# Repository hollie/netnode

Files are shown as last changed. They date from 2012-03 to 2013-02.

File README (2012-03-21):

This is the repository for the netnode project. 

WHAT IS THIS?
-------------

The netnode is an Ethernet-connected microcontroller. It is designed as a generic electronics platform that can be used to automate various tasks in and around the house.

The first version is built around a Microchip PIC microcontroller and a LanTronix XPORT serial to Ethernet convertor.

In this form, the netnode is running for over 5 years at our home. It is used to control electrical blinds, to measure temperatures in our HVAC system, to monitor our solar heating installation, to measure the output of a photovoltaic installation and to interface to wireless sensors.

The latest developments around the netnode focus on adding a standard interface for reporting sensors data and to control basic devices. The selected standard is xPL, because it allows coupling the netnode to a vast amount of existing software such as e.g. Misterhouse.

This repository is divided in three sections: 
 * hardware: the hardware design files of the netnode. The netnode is designed in Eagle and the design is open source (see license below).
 * firmware: the firmware for the controller on the netnode. Currently there is only a single subfolder here. All existing firmware is mapped on a netnode v1.x that is based on a Microchip PIC18F controller.
 * software: various host software packages used to interface to a netnode running a certain firmware. Most of the subfolders here implement a kind of datalogging functionality to RRD databases.
    
AUTHOR
------

Lieven Hollevoet designed the netnode at the time he was building his house. His goal was to build a low-energy home, and setting such a goal of course implies deploying a measurement network to check if the efforts were worthwhile. 
After experimenting with a CAN-based solution, he decided Ethernet was the way to go. The main reasons to go for Ethernet were that the cabling was already present, and that on the computer interface side Ethernet is an interface that is available on every computing device, opposed to CAN which isn't. 

CREDITS
-------

Some 'like-minded' people have contributed to the codebase. 

Dirk Buekenhoudt helped in coding and debugging the xPL interface code. He is currently working on adding digital inputs and outputs.

Roeland Vandebriel wrote the initial code for the SHT7x humidity sensors and is working on merging my Technische Alternative DL output interface code that I initially wrote for my TA UVR61-1. He is working on interfacing to the TA UVR1611.

DEMO
----

A demo of what measurements are done using netnode hardware can be found here:
http://lika.be/uushuus_stats/live.htm

LICENSE
-------

All work in this repository is available under the Creative Commons 
Attribution-NonCommercial-ShareAlike license 3.0.

http://creativecommons.org/licenses/by-nc-sa/3.0/

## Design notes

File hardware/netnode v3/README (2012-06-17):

Specifications of the Netnode v3
================================

Ethernet-connected PIC microcontroller

Highlights:
-----------
* Input voltage: 5 - 30 V, short circuit protected
* 10/100 Ethernet connection configurable through web interface on port 80
* System voltage: 3V3
* Can deliver up to 600 mA to target application.
* Typical power consumption: 0.92 W with ethernet running in normal performance mode
* 8-pin screw terminal connector with 4 GPIOs + ground connected to interrupt pins
* 8-pin screw terminal connector with I2C, 1 PWM, 1 optically isolated input, 1 one-wire bus, 3V3 and GND 
* 4 analog input pins broken out to non-populated header
* ICSP header on board
* Second serial port broken out to header to be able to easily connect XBee radio modules
* PIC has bootloader that allows firmware upgrades over the ethernet interface (*)
* optically isolated input designed for 12V input level (level can be changed by replacing a resistor)
* Open hardware, you're invited to thinker with it. 

Description:
------------
This is a PIC board that was developed to monitor the energy consumption and temperatures in and around our house. Multiple firmwares are available that can be loaded to have the board perform the functionality that is required.

Available firmwares are:
------------------------
 * one-wire to xPL bridge. Allows connecting one-wire temperature sensors, reports their status over xPL for easy integration with existing xPL software (e.g. Misterhouse). Plug the device in your network and the sensors appear in the software.
 * one-wire and SHTxx relative humidity to Cosm bridge. Idem as previous, but reports the sensor status to Cosm.com (previously Pachube). Ideal for people that don't have or want to keep a home server running to report sensor values to Cosm.
 * Technische Alternative solar heating controller interface (TA UVR61-3 and alike). Reports the status of your controller and the attached sensors over xPL (*).
 * TA to Cosm bridge. Idem as previous but reports to Cosm.com instead (*).

*: to be implemented

All work in this folder is available under the Creative Commons 
Attribution-NonCommercial-ShareAlike license 3.0.

http://creativecommons.org/licenses/by-nc-sa/3.0/

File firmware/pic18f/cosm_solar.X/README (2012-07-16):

This firmware turns the Netnode into a device that reports solar installation production to Cosm.com

The idea is to connect the netnode to the pulse output of the solar energy production meter.

This code is developed by Lieven Hollevoet. More info on http://likatronix.be

This work is licensed under the following license: 
  http://creativecommons.org/licenses/by-nc-sa/3.0/

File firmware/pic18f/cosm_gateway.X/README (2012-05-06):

This firmware turns the Netnode into a sensor device that reports status to Cosm.com

It supports Sensirion SHTxx relative humidity sensors, pulse counts, and OneWire temperature devices.

Example feed:
https://cosm.com/feeds/55686

This code is developed by Lieven Hollevoet. More info on http://likatronix.be

This work is licensed under the following license: 
  http://creativecommons.org/licenses/by-nc-sa/3.0/

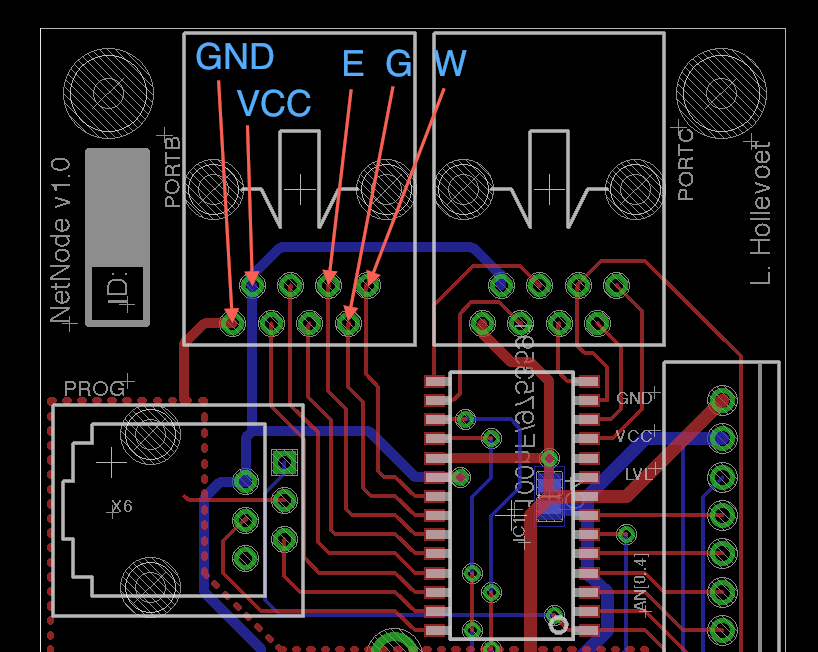
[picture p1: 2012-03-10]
firmware/pic18f/utility_monitor/doc/connections_netnode.png

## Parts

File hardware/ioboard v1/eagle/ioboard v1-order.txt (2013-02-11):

Order list for /Users/lieven/projects/likatronix/netnode/hardware/ioboard v1/eagle/ioboard v1.sch
Exported from EAGLE with DesignLink

Quantity	Value	Package	Order code	Manufacturer	Manuf. Code	Availability	Price (from)	Description
2		C0805	499158	AVX	08051A100JAT2A	4021	0.023	AVX - 08051A100JAT2A - CAPACITOR, 0805, 10PF, 100V
1	MCP23017SO	SO28W	1332087	MICROCHIP	MCP23017-E/SO	2802	0.86	MICROCHIP - MCP23017-E/SO - 16BIT EXPANDER, I/O, I2C I'F, SMD
1		DIL18	1047761	TOSHIBA	ULN2803APG	3340	0.86	TOSHIBA - ULN2803APG - DARLINGTON ARRAY 8NPN, DIP18, 50V
2	ACPL-244	SO16	1634755	AVAGO TECHNOLOGIES	ACPL-244-500E	2927	0.81	AVAGO TECHNOLOGIES - ACPL-244-500E - OPTOCOUPLER, QUAD, AC I/P, SO-16
2	691402910008	691402910008	unknown					
1	61300611021	61300611021	unknown					
1	613006143121	613006143121	unknown					
1	691214110003	691214110003	1841251	WURTH ELEKTRONIK	691214110003	175	0.71	WURTH ELEKTRONIK - 691214110003 - T/BLOCK, 3.5MM, HORIZ, PCB, 3WAY
16		CHIPLED_1206	unknown					
1		R0805	unknown					
7		RN8P-4R-CRA06S	unknown					
1		SJ	unknown					
1	418127270903	418127270903	unknown

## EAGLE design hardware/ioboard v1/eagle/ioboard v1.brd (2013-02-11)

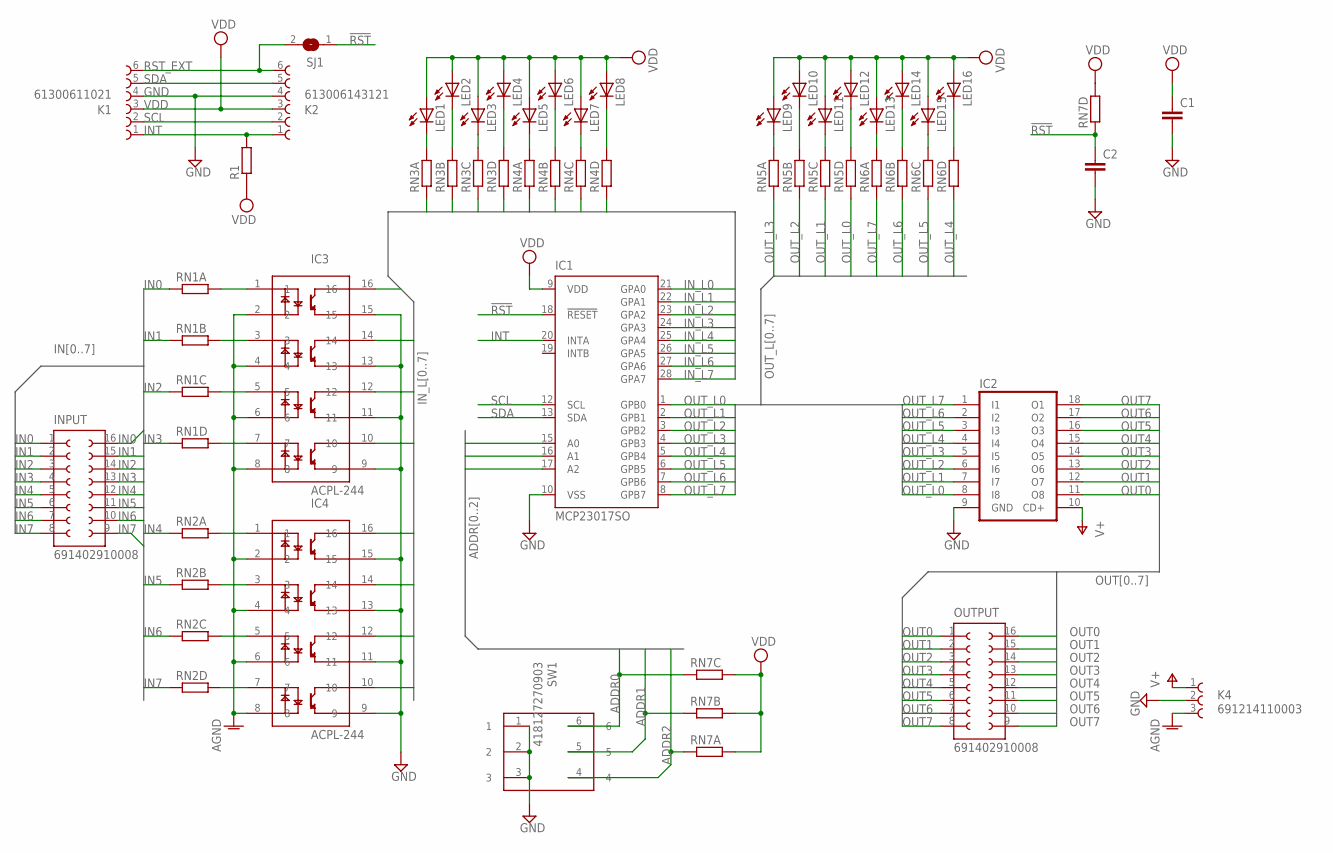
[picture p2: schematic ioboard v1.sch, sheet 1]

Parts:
C1, C2: C-EUC0805; C0805; MPN 08051A100JAT2A
IC1: MCP23017SO; SO28W; MPN MCP23017-E/SO
IC2: ULN2803A; DIL18; MPN ULN2803APG
IC3, IC4: ACPL-244; SO16; MPN ACPL-244-500E
INPUT: 691402910008
K1: 61300611021
K2: 613006143121
K4: 691214110003; MPN 691214110003
LED1, LED2, LED3, LED4, LED5, LED6, LED7, LED8, LED9, LED10, LED11, LED12, LED13, LED14, LED15, LED16: LEDCHIPLED_1206; CHIPLED_1206
OUTPUT: 691402910008
R1: R-EU_R0805; R0805
RN1, RN2, RN3, RN4, RN5, RN6, RN7: RESISTOR_ARRAY_4; RN8P-4R-CRA06S
SJ1: SJ
SW1: 418127270903

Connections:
!RST: C2.1, IC1.18 (!RESET), RN7.4 (1), SJ1.1
ADDR0: IC1.15 (A0), RN7.3 (1), SW1.6
ADDR1: IC1.16 (A1), RN7.2 (1), SW1.5
ADDR2: IC1.17 (A2), RN7.1, SW1.4
AGND: IC3.2, IC3.4, IC3.6, IC3.8, IC4.2, IC4.4, IC4.6, IC4.8, K4.3
GND: C1.2, C2.2, IC1.10 (VSS), IC2.9 (GND), IC3.9, IC3.11, IC3.13, IC3.15, IC4.9, IC4.11, IC4.13, IC4.15, K1.4, K2.4, K4.2, SW1.1, SW1.2, SW1.3
IN0: INPUT.1, INPUT.16, RN1.1
IN1: INPUT.2, INPUT.15, RN1.2 (1)
IN2: INPUT.3, INPUT.14, RN1.3 (1)
IN3: INPUT.4, INPUT.13, RN1.4 (1)
IN4: INPUT.5, INPUT.12, RN2.1
IN5: INPUT.6, INPUT.11, RN2.2 (1)
IN6: INPUT.7, INPUT.10, RN2.3 (1)
IN7: INPUT.8, INPUT.9, RN2.4 (1)
INT: IC1.20 (INTA), K1.1, K2.1, R1.2
IN_L0: IC1.21 (GPA0), IC3.16, RN3.1
IN_L1: IC1.22 (GPA1), IC3.14, RN3.2 (1)
IN_L2: IC1.23 (GPA2), IC3.12, RN3.3 (1)
IN_L3: IC1.24 (GPA3), IC3.10, RN3.4 (1)
IN_L4: IC1.25 (GPA4), IC4.16, RN4.1
IN_L5: IC1.26 (GPA5), IC4.14, RN4.2 (1)
IN_L6: IC1.27 (GPA6), IC4.12, RN4.3 (1)
IN_L7: IC1.28 (GPA7), IC4.10, RN4.4 (1)
unnamed: IC3.1, RN1.8 (2)
unnamed: IC3.3, RN1.7 (2)
unnamed: IC3.5, RN1.6 (2)
unnamed: IC3.7, RN1.5 (2)
unnamed: IC4.1, RN2.8 (2)
unnamed: IC4.3, RN2.7 (2)
unnamed: IC4.5, RN2.6 (2)
unnamed: IC4.7, RN2.5 (2)
unnamed: LED1.C, RN3.8 (2)
unnamed: LED2.C, RN3.7 (2)
unnamed: LED9.C, RN5.8 (2)
unnamed: LED10.C, RN5.7 (2)
unnamed: LED11.C, RN5.6 (2)
unnamed: LED12.C, RN5.5 (2)
unnamed: LED3.C, RN3.6 (2)
unnamed: LED4.C, RN3.5 (2)
unnamed: LED13.C, RN6.8 (2)
unnamed: LED14.C, RN6.7 (2)
unnamed: LED15.C, RN6.6 (2)
unnamed: LED16.C, RN6.5 (2)
unnamed: LED5.C, RN4.8 (2)
unnamed: LED6.C, RN4.7 (2)
unnamed: LED7.C, RN4.6 (2)
unnamed: LED8.C, RN4.5 (2)
OUT0: IC2.11 (O8), OUTPUT.1, OUTPUT.16
OUT1: IC2.12 (O7), OUTPUT.2, OUTPUT.15
OUT2: IC2.13 (O6), OUTPUT.3, OUTPUT.14
OUT3: IC2.14 (O5), OUTPUT.4, OUTPUT.13
OUT4: IC2.15 (O4), OUTPUT.5, OUTPUT.12
OUT5: IC2.16 (O3), OUTPUT.6, OUTPUT.11
OUT6: IC2.17 (O2), OUTPUT.7, OUTPUT.10
OUT7: IC2.18 (O1), OUTPUT.8, OUTPUT.9
OUT_L0: IC1.1 (GPB0), IC2.8 (I8), RN5.4 (1)
OUT_L1: IC1.2 (GPB1), IC2.7 (I7), RN5.3 (1)
OUT_L2: IC1.3 (GPB2), IC2.6 (I6), RN5.2 (1)
OUT_L3: IC1.4 (GPB3), IC2.5 (I5), RN5.1
OUT_L4: IC1.5 (GPB4), IC2.4 (I4), RN6.4 (1)
OUT_L5: IC1.6 (GPB5), IC2.3 (I3), RN6.3 (1)
OUT_L6: IC1.7 (GPB6), IC2.2 (I2), RN6.2 (1)
OUT_L7: IC1.8 (GPB7), IC2.1 (I1), RN6.1
RST_EXT: K1.6, K2.6, SJ1.2
SCL: IC1.12 (SCL), K1.2, K2.2
SDA: IC1.13 (SDA), K1.5, K2.5
V+: IC2.10 (CD+), K4.1
VDD: C1.1, IC1.9 (VDD), K1.3, K2.3, LED1.A, LED2.A, LED3.A, LED4.A, LED5.A, LED6.A, LED7.A, LED8.A, LED9.A, LED10.A, LED11.A, LED12.A, LED13.A, LED14.A, LED15.A, LED16.A, R1.1, RN7.5 (2), RN7.6 (2), RN7.7 (2), RN7.8 (2)

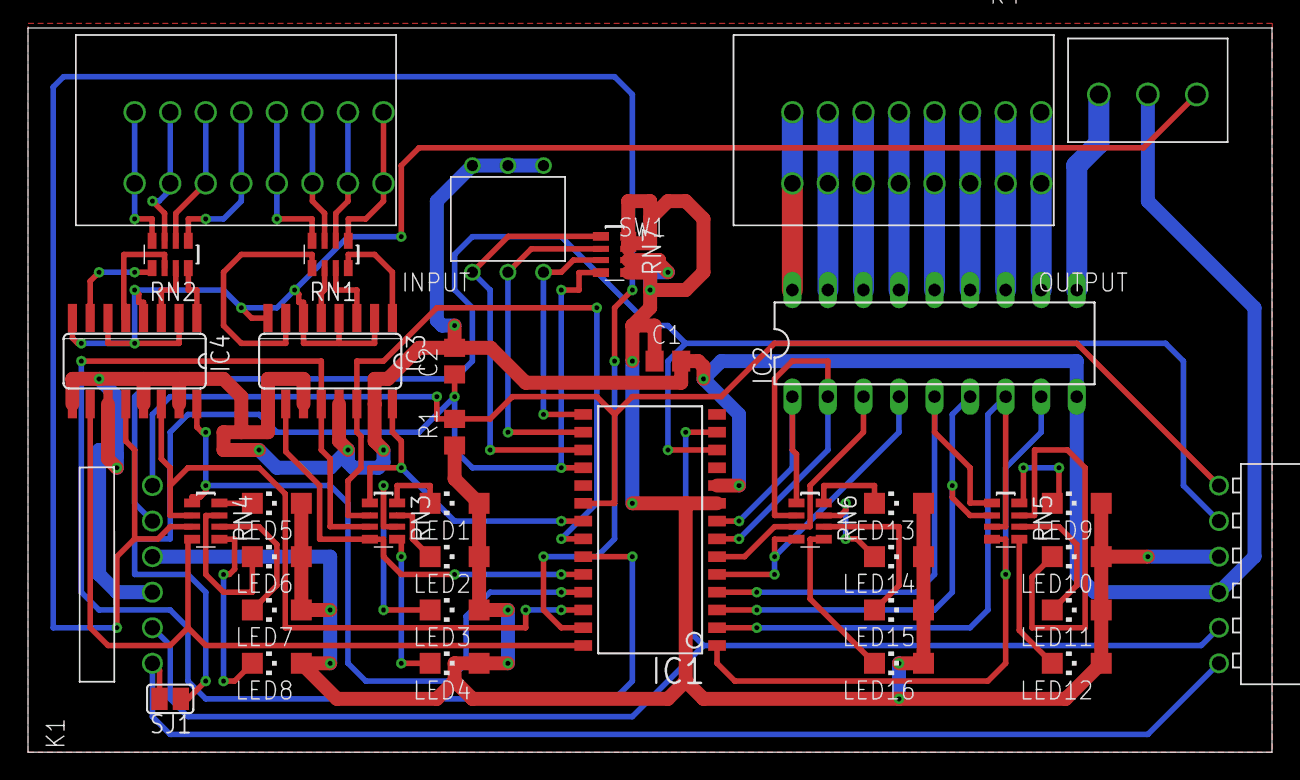
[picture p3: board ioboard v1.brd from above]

Board: 2 copper layers, 88.9 x 51.7 mm, 37 parts (0 on the bottom side), 68 nets.

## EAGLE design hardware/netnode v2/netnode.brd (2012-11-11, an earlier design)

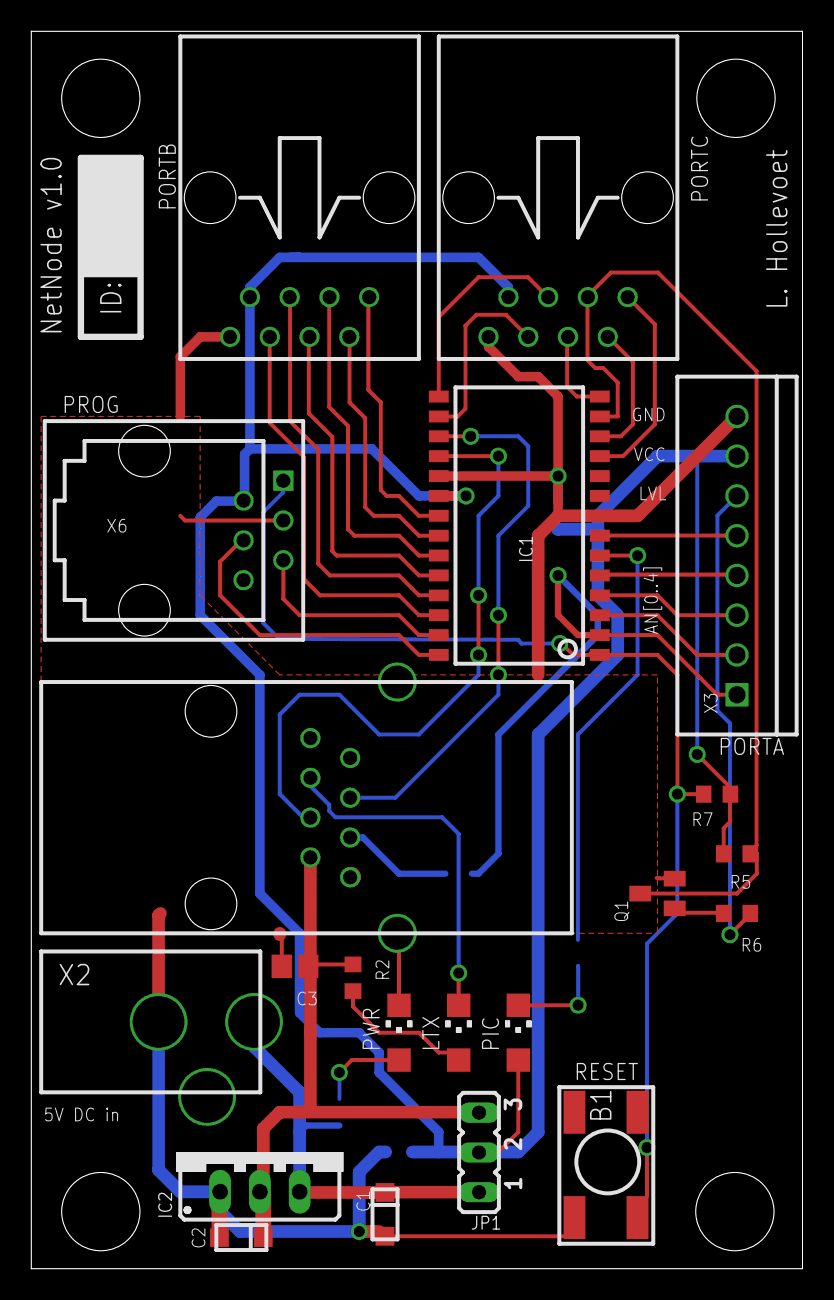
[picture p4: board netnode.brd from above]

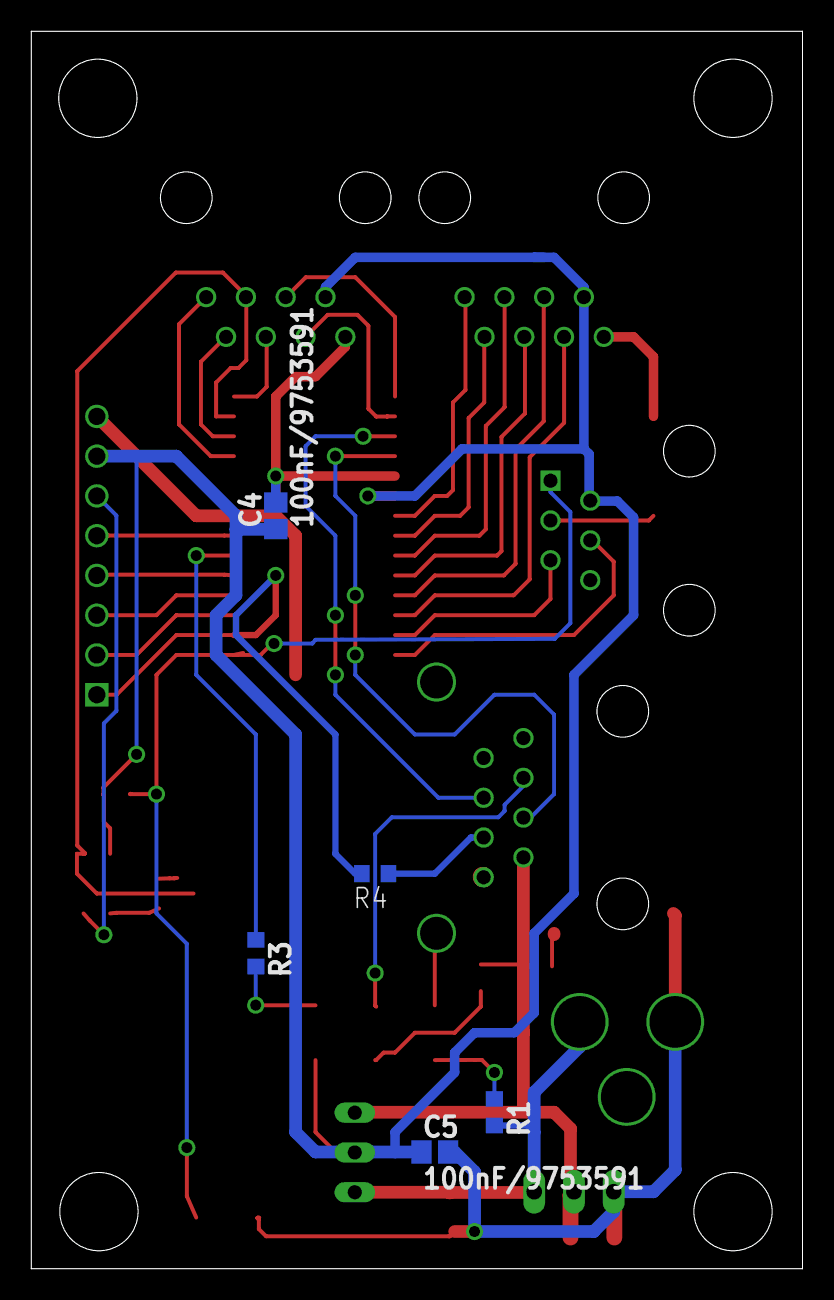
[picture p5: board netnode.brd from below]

Board: 4 copper layers, 49.3 x 79.0 mm, 26 parts (5 on the bottom side), 34 nets.

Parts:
B1: 9902031; PUSHBUTTON
C1, C2: 10u/7565127; CHIPCAP
C3, C4, C5: 100nF/9753591; C0805
IC1: PIC18F2320/9762051; SO-28W
IC2: 1087165; 78XXS
JP1: JP2
LTX: CHIPLED_1206
PIC: CHIPLED_1206
PWR: CHIPLED_1206
Q1: 1081235; SOT23
R1, R2, R3: R0603
R4: 0; R0603
R5: 10k/9331700; R0603
R6: 470k/612807RL; R0603
R7: 1k/9331697RL; R0603
X1: XPORT
X2: DC10R/224959; DC10R
X3: SCREW_TERMINAL/3041438; SCREW_TERMINAL_8PINS
X4, X5: RJ45H
X6: X/1097917; RJ11

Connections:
+3V3: C2.+, C3.1, IC2.GND, JP1.3, R2.2, X1.2
+5V: C1.+, IC2.OUT, JP1.1, R1.2, X2.1
AN0: IC1.2, R4.2, X3.1
AN1: IC1.3, X3.2
AN2: IC1.4, X3.3
AN3: IC1.5, X3.4
AN4: IC1.7, X3.5
CP1: LTX.C, X1.6
GND: B1.1, C1.-, C2.-, C3.2, C4.2, C5.2, IC1.8, IC1.19, IC2.IN, PWR.C, Q1.2, X1.1, X1.TAB1, X1.TAB2, X2.3, X3.8, X4.P$8, X5.P$8, X6.3
LVL: R6.2, X3.6
MCLR: B1.3, IC1.1, R7.2, X6.1
unnamed: Q1.1, R6.1
unnamed: PWR.A, R1.1
unnamed: R4.1, X1.3
unnamed: LTX.A, R2.1
PIC: PIC.C, R3.2
PIC_RX: IC1.18, X1.4
PIC_TX: IC1.17, X1.5
RA4: IC1.6, R3.1
RB0: IC1.21, X4.P$1
RB1: IC1.22, X4.P$2
RB2: IC1.23, X4.P$3
RB3: IC1.24, X4.P$4
RB4: IC1.25, X4.P$5
RB5: IC1.26, X4.P$6
RB6: IC1.27, X6.5
RB7: IC1.28, X6.4
RC0: IC1.11, X5.P$1
RC1: IC1.12, X5.P$2
RC2: IC1.13, Q1.3, R5.1, X5.P$3
RC3: IC1.14, X5.P$4
RC4: IC1.15, X5.P$5
RC5: IC1.16, X5.P$6
VCC: C4.1, C5.1, IC1.20, JP1.2, PIC.A, R5.2, R7.1, X3.7, X4.P$7, X5.P$7, X6.2

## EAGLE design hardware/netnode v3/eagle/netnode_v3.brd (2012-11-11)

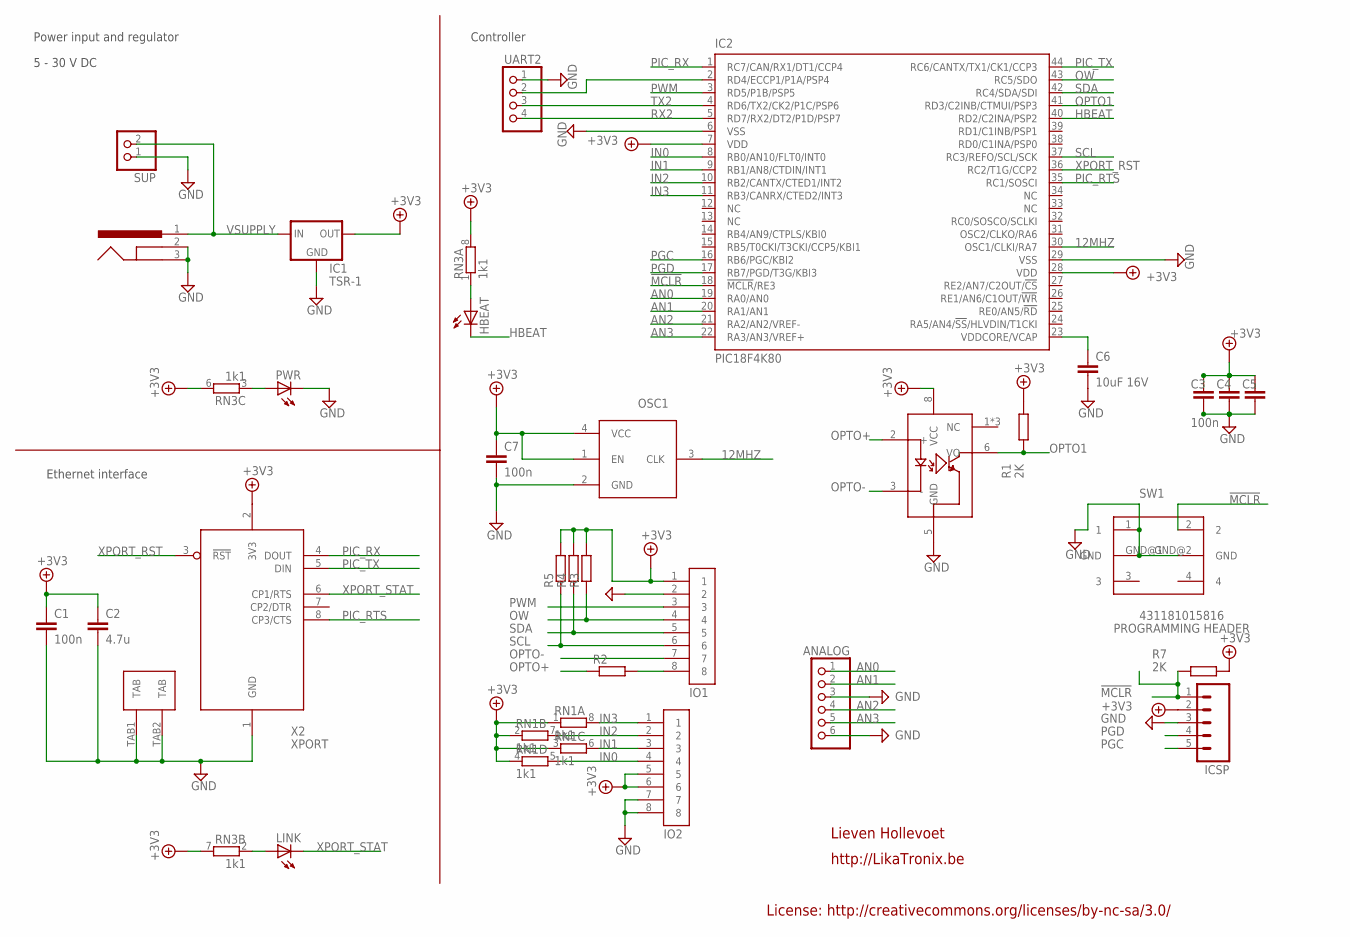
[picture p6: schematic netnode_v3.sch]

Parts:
ANALOG: PINHD-1X6; 1X06
C1, C3, C4, C5, C7: 100n; C0805; MPN 08055C104JAT2A
C2: 4.7u; C0805; MPN 0805YD475KAT2A
C6: 10uF 16V; C1206; MPN C1206C106K4PAC-TU
HBEAT: LEDCHIPLED_1206; CHIPLED_1206; MPN KP-3216EC
IC1: TSR-1; TSR1-SIPS; MPN TSR 1-2433
IC2: PIC18F4K80; TQFP44; MPN PIC18F45K80-I/PT
IC3: FOD060L; SO-08
ICSP: ICSP; 1X05
IO1, IO2: SCREW_TERMINAL; SCREW_TERMINAL_8PINS; MPN 1725711
LINK: LEDCHIPLED_1206; CHIPLED_1206; MPN KP-3216EC
OSC1: TXC - 7X-12.000MBB-T; 7W_7X5; MPN 7X-12.000MBB-T
PWR: LEDCHIPLED_1206; CHIPLED_1206; MPN KP-3216EC
R1, R7: 2K; R0805; MPN CR0603-FX-2001ELF
R2: R-EU_M0805; M0805
R3, R4, R5: R-EU_R0603; R0603
RN1, RN3: 1k1; RN8P-4R-CRA06S; MPN EXB38V102JV
SUP: PINHD-1X2; 1X02
SW1: 431181015816
UART2: PINHD-1X4; 1X04
X1: DC10R; MPN DC10A
X2: XPORT

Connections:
12MHZ: IC2.30 (OSC1/CLKI/RA7), OSC1.3 (CLK)
!MCLR: IC2.18 (!MCLR!/RE3), ICSP.1, R7.1, SW1.2
+3V3: C1.1, C2.1, C3.1, C4.1, C5.1, C7.1, IC1.3 (OUT), IC2.7 (VDD), IC2.28 (VDD), IC3.8 (VCC), ICSP.2, IO1.1, IO2.5, IO2.6, OSC1.1 (EN), OSC1.4 (VCC), R1.2, R3.2, R4.2, R5.2, R7.2, RN1.1, RN1.2 (1), RN1.3 (1), RN1.4 (1), RN3.6 (2), RN3.7 (2), RN3.8 (2), X2.2 (3V3)
AN0: ANALOG.1, IC2.19 (RA0/AN0)
AN1: ANALOG.2, IC2.20 (RA1/AN1)
AN2: ANALOG.4, IC2.21 (RA2/AN2/VREF-)
AN3: ANALOG.5, IC2.22 (RA3/AN3/VREF+)
GND: ANALOG.3, ANALOG.6, C1.2, C2.2, C3.2, C4.2, C5.2, C6.2, C7.2, IC1.2 (GND), IC2.6 (VSS), IC2.29 (VSS), IC3.5 (GND), ICSP.3, IO1.2, IO2.7, IO2.8, OSC1.2 (GND), PWR.C, SUP.1, SW1.1, SW1.GND@1 (GND), SW1.GND@2 (GND), UART2.1, X1.2 (CONTACT), X1.3 (SHIELD), X2.1 (GND), X2.TAB1 (TAB), X2.TAB2 (TAB)
HBEAT: HBEAT.C, IC2.40 (RD2/C2INA/PSP2)
IN0: IC2.8 (RB0/AN10/FLT0/INT0), IO2.4, RN1.5 (2)
IN1: IC2.9 (RB1/AN8/CTDIN/INT1), IO2.3, RN1.6 (2)
IN2: IC2.10 (RB2/CANTX/CTED1/INT2), IO2.2, RN1.7 (2)
IN3: IC2.11 (RB3/CANRX/CTED2/INT3), IO2.1, RN1.8 (2)
unnamed: LINK.A, RN3.2 (1)
unnamed: PWR.A, RN3.3 (1)
unnamed: HBEAT.A, RN3.1
OPTO1: IC2.41 (RD3/C2INB/CTMUI/PSP3), IC3.6 (VO), R1.1
OPTO+: IC3.2 (+), R2.1
OPTO+_PRE_RES: IO1.8, R2.2
OPTO-: IC3.3 (-), IO1.7
OW: IC2.43 (RC5/SDO), IO1.4, R3.1
PGC: IC2.16 (RB6/PGC/KBI2), ICSP.5
PGD: IC2.17 (RB7/PGD/T3G/KBI3), ICSP.4
PIC_RTS: IC2.35 (RC1/SOSCI), X2.8 (CP3/CTS)
PIC_RX: IC2.1 (RC7/CAN/RX1/DT1/CCP4), X2.4 (DOUT)
PIC_TX: IC2.44 (RC6/CANTX/TX1/CK1/CCP3), X2.5 (DIN)
PWM: IC2.3 (RD5/P1B/PSP5), IO1.3
RD4: IC2.2 (RD4/ECCP1/P1A/PSP4), UART2.2
RX2: IC2.5 (RD7/RX2/DT2/P1D/PSP7), UART2.4
SCL: IC2.37 (RC3/REFO/SCL/SCK), IO1.6, R5.1
SDA: IC2.42 (RC4/SDA/SDI), IO1.5, R4.1
TX2: IC2.4 (RD6/TX2/CK2/P1C/PSP6), UART2.3
VDDCAP: C6.1, IC2.23 (VDDCORE/VCAP)
VSUPPLY: IC1.1 (IN), SUP.2, X1.1 (CENTER)
XPORT_RST: IC2.36 (RC2/T1G/CCP2), X2.3 (!RST)
XPORT_STAT: LINK.C, X2.6 (CP1/RTS)

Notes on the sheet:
Power input and regulator
5 - 30 V DC
Ethernet interface
PROGRAMMING HEADER
Lieven Hollevoet
http://LikaTronix.be
License: http://creativecommons.org/licenses/by-nc-sa/3.0/
Controller

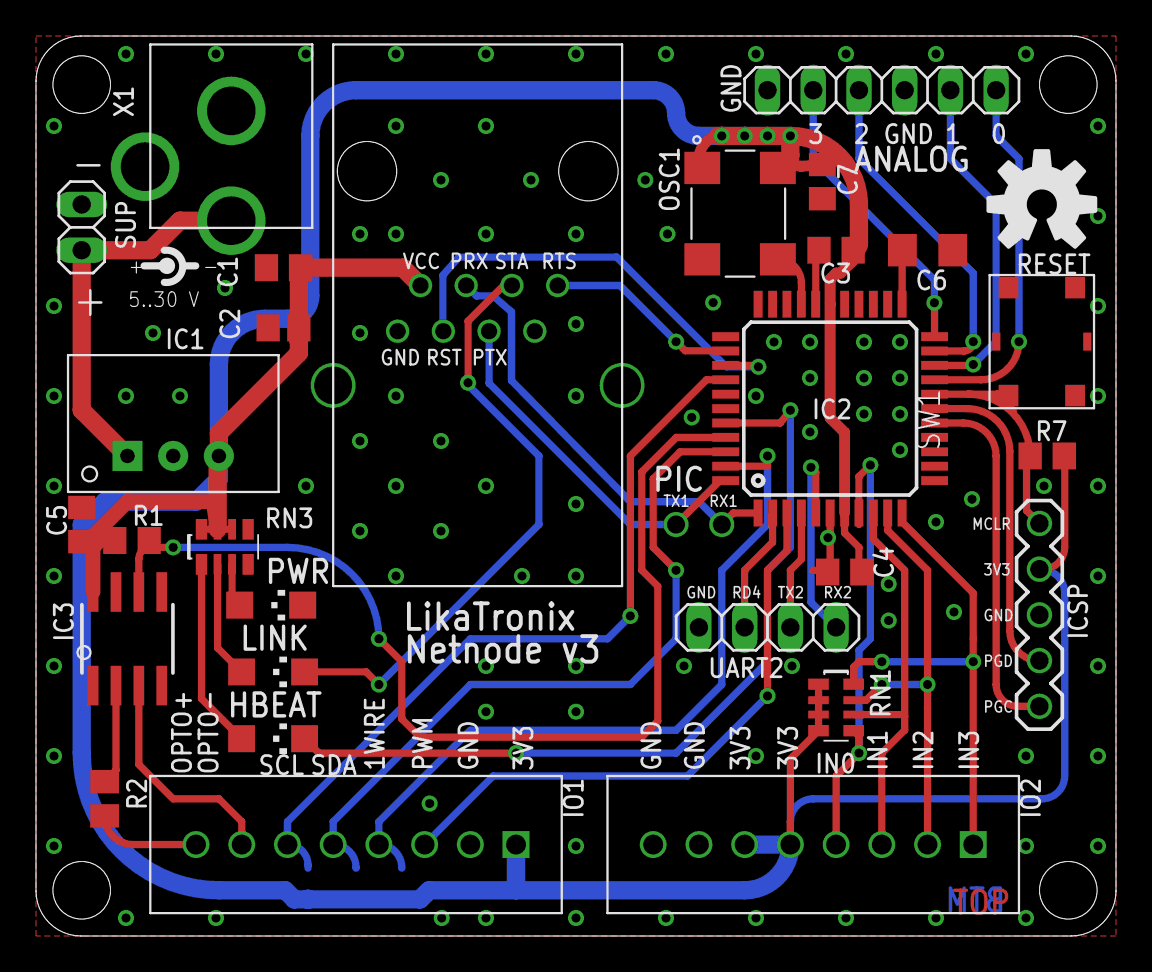
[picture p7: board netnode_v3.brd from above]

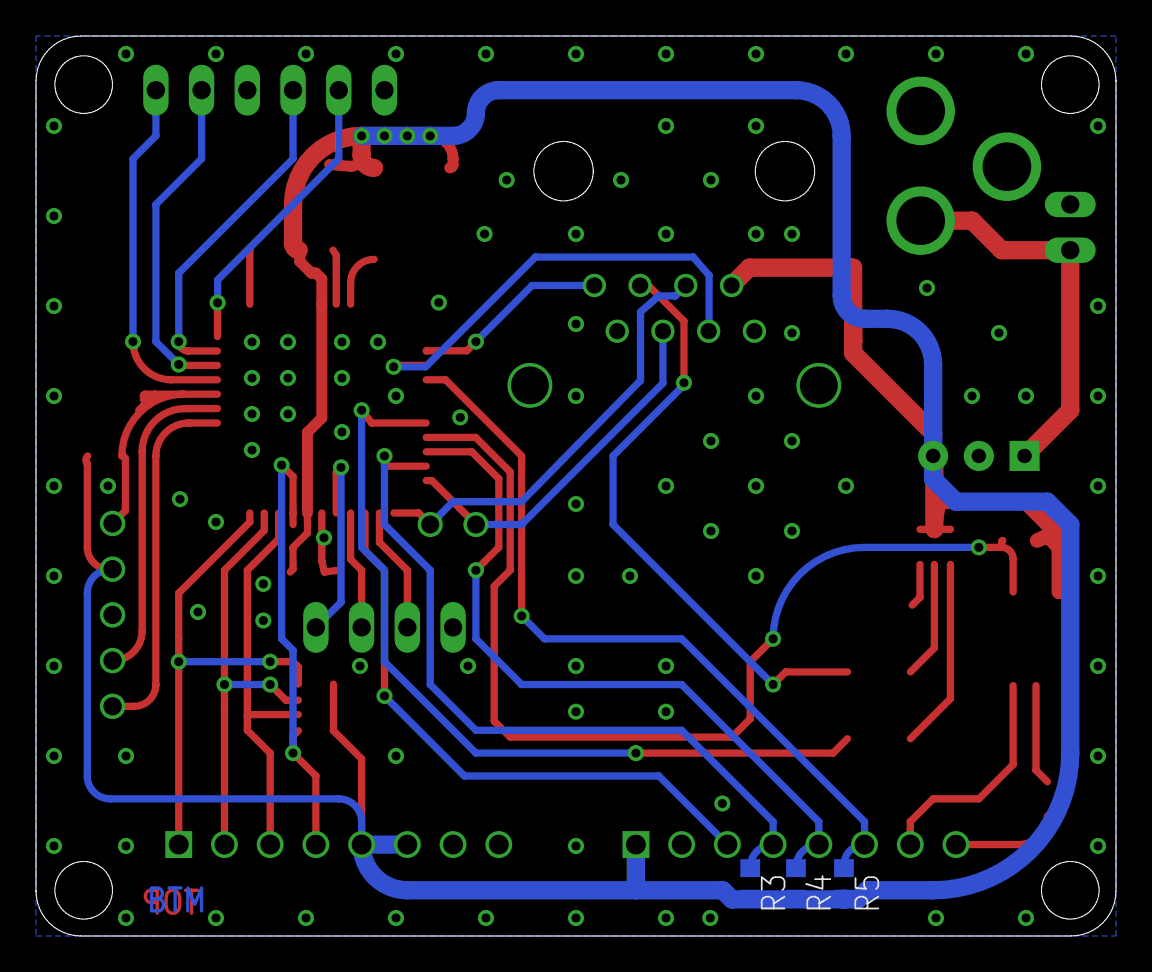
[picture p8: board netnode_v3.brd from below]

Board: 2 copper layers, 60.0 x 50.0 mm, 31 parts (3 on the bottom side), 36 nets.

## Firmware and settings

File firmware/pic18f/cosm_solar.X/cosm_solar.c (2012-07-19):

/*************************************************************
 * Cosm gateway
 *
 * Monitors the inputs INT0..2 and counts pulses on them.
 * Performs debouncing before the count is incremented
 *
 * (c) Lieven Hollevoet, LikaTronix.be
 *
 * License: http://creativecommons.org/licenses/by-nc-sa/3.0/
 **************************************************************
 * target device   : PIC18F2520/PIC18F2580
 * clockfreq       : 32 MHz (internal oscillator + PLL)
 * target hardware : NetNode v2
 * UART speed      : 38400 bps
 * IDE             : MPLABX
 * Compiler        : C18 v3.40
 *************************************************************/

#include <p18cxxx.h>
#include <usart.h>
#include <delays.h>
#include <timers.h>
#include <pwm.h>
#include <stdio.h>

#include "fuses.h"
#include "cosm_solar.h"
#include "../likalibs.X/oo.h"
#include "../likalibs.X/eeprom.h"
#include "../likalibs.X/cosm_socket.h"


// Global variables used for message passing between ISR and main code
// Set time_ticks to 50 so that we try to connect after 10 seconds the first time
volatile unsigned short time_ticks = 350;
volatile unsigned char time_ticks_oo = 0;
volatile unsigned char time_ticks_sht = 0;

volatile unsigned char debounce_water;
volatile unsigned char debounce_gas;
volatile unsigned char debounce_elec;

volatile unsigned short elec_pulses;

enum DEVICE_CONFIGURATION {
    \\
        SHT_PRESENT = 1, \\
        ONE_WIRE_PRESENT = 2, \\
        };

char hw_config = 0; /* mapped with DEVICE_CONFIGURATION
                                            bit 0 = sht_present
                                            bit 1 = one wire present
                    */

char sensor_name[2][12] = {"generated", "dummy"};
//char cosm_api_key[64] = "OivrtCBI0vaCBGTN46ktyluuoqeSAKxzZXlZUEdzdGlRYz0g";
char cosm_api_key[64] = "HelloWorld";

unsigned int cosm_feed_id  = 67597;

//////////////////////////////////////////////////////////////////
// Main loop
// Program strategy:
// * report the sensor status every minute to Cosm.com

void main() {

    signed short sht_temp;
    unsigned char sht_humi;
    unsigned short elec_report;

    // Hardware initialisation
    init();


    // Get configuration settings from EEPROM
    eeprom_read_block(MEM_API_KEY, cosm_api_key, sizeof cosm_api_key);
    //eeprom_write_ulong(MEM_FEED_ID, 67597);
    eeprom_read_block(MEM_FEED_ID, &cosm_feed_id, sizeof cosm_feed_id);

    elec_pulses = 0;
    elec_report = 0;
    // Check presence of sensors
    // Init the helper libraries so that we know if need the
    // library specific code
    /*if (!oo_init()) {
        hw_config |= ONE_WIRE_PRESENT;
        oo_read_temperatures();
    }

    if (sht_init() == 0) {
        hw_config|= SHT_PRESENT;
    }
*/

    // Init the Cosm library
    cosm_init(cosm_api_key, cosm_feed_id);


    while (1) {

        // Check if we need to report (every 5 minutes)
        if (time_ticks > 359) {
            stat0 = 0;
            time_ticks = 0;

            /*

            if (hw_config & SHT_PRESENT) {
                sht_do_measure();
                sht_temp = sht_get_temperature();
                sht_humi = sht_get_humidity();

                cosm_report(sensor_name[0], sht_humi, 0);
                cosm_report(sensor_name[1], sht_temp, 1);

            }
            stat0 = 1;
             */

            // Calculate the average power over the last 5 minute interval
            // and report
            elec_report = elec_pulses;
            cosm_report(sensor_name[0], elec_report*12, 0);
            elec_pulses = elec_pulses - elec_report;


        }

    }

}

//////////////////////////////////////////////////////////////////
// Hardware initialisation routine

void init(void) {

    char blink_count = 0;

    // Oscillator selection
    OSCCONbits.IRCF0 = 1;
    OSCCONbits.IRCF1 = 1;
    OSCCONbits.IRCF2 = 1;
    OSCTUNEbits.PLLEN = 1;

    // All digital IO's on port A
    ADCON1 = 0x0F;

    // Set port direction bits
    TRISA = PortAConfig;
    TRISB = PortBConfig;
    TRISC = PortCConfig;

    // Serial interface init (38400 @ 32 MHz, BRGH = 1 => 51)
    OpenUSART(USART_ASYNCH_MODE &
            USART_TX_INT_OFF &
            USART_RX_INT_ON &
            USART_EIGHT_BIT &
            USART_CONT_RX &
            USART_BRGH_HIGH,
            51);

    // Do the status LED flicker
  /*  while (blink_count++ < 5) {
        Delay10KTCYx(50);
        stat0 = 0;
        Delay10KTCYx(50);
        stat0 = 1;
    }
*/
    // Enable the main 1-sec timer that will interrupt every second
    OpenTimer0(TIMER_INT_ON &
            T0_16BIT &
            T0_SOURCE_INT &
            T0_PS_1_256);

    WriteTimer0(TMR0_VALUE); // Load initial timer value


    // Prepare the 20 ms debouncing timer for the inputs
    OpenTimer1(TIMER_INT_ON &
            T1_16BIT_RW &
            T1_SOURCE_INT &
            T1_PS_1_8 &
            T1_OSC1EN_OFF);

    WriteTimer1(TMR1_VALUE);

    // Enable pullups on Portb inputs
    INTCON2bits.RBPU = 0; // (bit is active low!)

    // Enable interrupt on falling edge of RB0/1/2
    INTCON2bits.INTEDG0 = 0; // Interrupt on falling edge
    INTCON2bits.INTEDG1 = 0; // Interrupt on falling edge
    INTCON2bits.INTEDG2 = 0; // Interrupt on falling edge

    // Reset interrupt flags and enable the interrupts
    INTCONbits.INT0IF = 0; // Reset interrupt
    INTCONbits.INT0IE = 1; // Clear mask bit
    INTCON3bits.INT1IF = 0;
    INTCON3bits.INT1IE = 1;
    INTCON3bits.INT2IF = 0;
    INTCON3bits.INT2IE = 1;

    INTCONbits.PEIE = 1; // Peripheral interrupt enable for USART RX interrupt
    INTCONbits.GIE = 1; // Global interrupt enable

}



//////////////////////////////////////////////////////////////////
// Interrupt service routines
//
// This is some ugly stuff, required by the C18 compiler to ensure
// that the both interrupt vectors contain valid goto instructions

// Generate the high-priority interrupt vector, and put a goto high_isr there
#pragma code high_vector=0x08

void high_interrupt(void) {
    _asm GOTO high_isr _endasm
}

#pragma code

#pragma interrupt high_isr

void high_isr(void) {

    /* USART RX INTERRUPT HANDLING */
    if (PIR1bits.RCIF == 1) {
        cosm_process_uart(ReadUSART());
        PIR1bits.RCIF = 0;
        return;
    }

    /* RB0 INTERRUPT HANDLING */
    if (INTCONbits.INT0IF == 1) {
        debounce_water = 2;
        INTCONbits.INT0IF = 0;
        stat0 = 0;
        return;
    }

    /* RB1 INTERRUPT HANDLING */
    if (INTCON3bits.INT1IF == 1) {
        debounce_gas = 2;
        INTCON3bits.INT1IF = 0;
        stat0 = 0;
        return;
    }

    /* RB2 INTERRUPT HANDLING */
    if (INTCON3bits.INT2IF == 1) {
        debounce_elec = 2;
        INTCON3bits.INT2IF = 0;
        stat0 = 0;
        return;
    }

    /* TIMER 0 INTERRUPT HANDLING */
    if (INTCONbits.TMR0IF == 1) {
        WriteTimer0(TMR0_VALUE); // Reprogram timer
        INTCONbits.TMR0IF = 0; // Clear interrupt flag
        time_ticks++;
        time_ticks_oo++;
        time_ticks_sht++;
    }

    /* TIMER 1 INTERRUPT HANDLING */
    if (PIR1bits.TMR1IF == 1) {
        WriteTimer1(TMR1_VALUE);
        PIR1bits.TMR1IF = 0;
        // Check if we need to handle a debounce
        if (debounce_water) {
            debounce_water--;
            stat0 = 1;
            if (debounce_water == 0 && PORTBbits.RB0 == 0) {
                //xpl_trig(WATER);
            }
        }

        if (debounce_gas) {
            debounce_gas--;
            stat0 = 1;
            if (debounce_gas == 0 && PORTBbits.RB1 == 0) {
                //xpl_trig(GAS);
            }
        }

        if (debounce_elec) {
            debounce_elec--;
            stat0 = 1;
            if (debounce_elec == 0 && PORTBbits.RB2 == 0) {
                //xpl_trig(ELEC);
                elec_pulses++;
            }
        }

    }

    return;
}

// Generate low-priority interrupt vector, and put a goto low_isr there
#pragma code low_vector=0x18

void low_interrupt(void) {
    _asm GOTO low_isr _endasm
}

#pragma code
#pragma interruptlow low_isr

void low_isr(void) {

}

void display_application_menu(char entry){
    switch (entry) {
        case 0:
           printf("Cosm Solar v%i.%i settings menu:\n", VER_MAJOR, VER_MINOR);
           printf("Current settings:\nFeed ID: %i\n", cosm_feed_id);
           printf("API key: %s\n", cosm_api_key);
           printf("Menu:\n\t[1] feed id\n\t[2] API key\n?");
        default:
            printf("Oops, invalid!\n");
    }
}

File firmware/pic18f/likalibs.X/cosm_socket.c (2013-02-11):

/*
 * Connect and send messages to the Cosm.com socket service
 * through a Lantronix XPort device
 *
 * Author: Lieven Hollevoet, LikaTronix.be
 *
 * License: http://creativecommons.org/licenses/by-nc-sa/3.0/
 */

#include <p18cxxx.h>
#include <usart.h>
#include <stdio.h>
#include <delays.h>
#include "cosm_socket.h"

extern void display_application_menu(char entry);

enum UART_STATE_TYPE { IDLE = 0, WAIT_CONNECT, CONNECTED, INCOMING, WAITING_INFO, STORE_STRING, STRING_RECEIVED, WAIT_FOR_DISCONNECT};
enum UART_STATE_TYPE uart_state;
short uart_length;

char* api_key;
unsigned long feed_id;


//////////////////////////////////////////////////////////////////
// Init the library
//////////////////////////////////////////////////////////////////
void cosm_init(char* auth_key, unsigned long feed) {
    uart_length=0;
    uart_state = IDLE;
    api_key = auth_key;
    feed_id = feed;
    return;
}


//////////////////////////////////////////////////////////////////
// Open a TCP connection through the XPORT
//////////////////////////////////////////////////////////////////

void cosm_connect(void) {

    char counter = 0;

    if (uart_state == IDLE) {
        uart_state = WAIT_CONNECT;
        printf("C216.52.233.122/8081\n"); // DNS is not working reliably, so we hardcode the server IP address here
        while (uart_state == WAIT_CONNECT) {
            counter++;
            // Sleep a while
            Delay10KTCYx(80);

            // Timeout, just in case we get stuck here.
            if (counter > 10 ) {
                uart_state = IDLE;
                return;
            }
        }
    }

    return;
}


//////////////////////////////////////////////////////////////////
// Send the current sensor information
// If we want to report a floating point value, we pass the
// value multiplied by 100 and we scale in this function
// by setting the scale value to '1'
//////////////////////////////////////////////////////////////////

void cosm_report(char *name, signed short value, char scale) {

    signed short value_abs;
    signed short value_whole;
    signed short value_part;

    cosm_connect();
    if (uart_state != CONNECTED) {
        return;
    }

    if (scale) {
        value_abs = value;
        if (value < 0) {
            value_abs = -value;
        }
        value_whole =  (value_abs / 100);
        value_part  =  (value_abs - value_whole * 100);
    }

    // Report the sensor value
    printf("{\n\"method\":\"put\",\n");
    printf("\"resource\":\"/feeds/%u\",\n",feed_id);
    printf("\"params\":{},\n");
    printf("\"headers\":{\"X-PachubeApiKey\":\"%s\"},\n", api_key);
    printf("\"body\":{\n \"version\":\"1.0.0\",\n \"datastreams\":[\n {\n  ");
    printf("\"id\":\"%s\",\n  ", name);
    printf("\"current_value\":\"");
    if (scale) {
        if (value < 0) {
            printf("-");
        }
        printf("%i.%02i", value_whole, value_part);
    } else {
        printf("%i", value);
    }
    printf("\"\n }\n ]\n},\n\"token\":\"testing*\"\n}\n");

    return;
}





///////////////////////////////////////////////////////////////////////
// State machine to process that UART input
// This function takes care of the interface towards the XPORT
// that has been put in 'manual connection' mode.
///////////////////////////////////////////////////////////////////////

void cosm_process_uart(char data) {

    uart_length++;

    switch (data) {
        case 'C': // When a connection is made, the XPORT sends a 'C'
            if (uart_state == WAIT_CONNECT || uart_state == IDLE) {
                uart_state = CONNECTED;
            }

            return;
        case 'I': // When the next character is an 'I', it is an active incoming connection. Handle it...
            if (uart_state == CONNECTED && uart_length == 2) {
                uart_state = INCOMING;
                //display_application_menu(0);
            }
            return;
        //case '*': // End of the string that needs to be stored
            //if (uart_state == STORE_STRING){
        //    uart_state = WAIT_FOR_DISCONNECT;
            //}
        //    return;
        case 'D':
            //if (uart_state == WAIT_FOR_DISCONNECT){
                uart_length=0;
                uart_state = IDLE;
            //    return;
            //}
        default:
            switch (uart_state) {
                case WAIT_CONNECT:
                    if (data == 'N') { // If the connection failed, reset the state machine
                        uart_state = IDLE;
                        uart_length = 0;
                        return;
                    }
                    break;
                case INCOMING:
                    if (data == '1') {
                        printf("Waiting for input 1\n");
                    }
                    if (data == '2') {
                        printf("Waiting for input 2\n");
                    }
                    break;
                default:
                    printf("Invalid choice\n");
                    return;

            }

    }

}

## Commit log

2012-03-10 Fixed the compiler warnings caused by different compilation options of the libs vs the code
    [shtxx.h, xpl.c]
2012-03-14 Added support for Sensirion SHTxx humidity sensors.
    Initial support for the sensors is added based on the code migrated by
    Roeland from my PSOC library.
    The readout is working and was reported through a non-standard xPL
    message.
    To be done: add xPL message support conform the specification.
    Bumped the firmware version to v4.6
2012-03-14 Started adding xPL compliant support for the SHT sensor
    Prepared the xPL lib for regularly polling the SHT sensor and to sense
    out xpl-trig messages when the reading changed.
    Bugfix: xpl_node_configuration was mistakingly reset completely in the
    init_instance_id function.
    [shtxx.h, utility_monitor.c, xpl.c]
2012-03-15 Added reporting of the SHT sensor readings to the xPL library
2012-03-15 SHT sensor reporting tested on hardware
2012-05-05 Updated test server for socket client testing
2012-05-12 Corrections for the decimals
    If the decimals where 09 or 0 something they where displayed without
    the 0
    [cosm_socket.c]
2012-05-12 Correct calculation of whole and part value's
    For negative numbers the value_whole and value_part where not
    calculated correctly.
    [cosm_socket.c]
2012-05-15 Added feed id to init function, bug fixed printing of scaled negative values.
    [cosm_gateway.c, cosm_socket.c]
2012-05-15 Updated gitignore and fixed a potential case where we miss the reporting condition due to condition not matching (unlikely, but better to be safe than to be sorry).
    [cosm_gateway.c]
2012-06-11 Intermediate release, schematic to be completed.
    [netnode_v3.brd, netnode_v3.sch]
2012-06-11 Backported bugfix fro Roeland
    [cosm_socket.c]
2012-06-15 Pre-final board files, silkscreen to be fixed
    [netnode_v3.brd, netnode_v3.sch]
2012-07-09 Further finalization of board
    [netnode_v3.brd, netnode_v3.sch]
2012-07-16 Completed order codes.
    [netnode_v3.brd, netnode_v3.sch]
2012-07-16 Added resistors and cleaned silkscreen
    [netnode_v3.brd]
2012-07-19 Further board cleanup
    * Silkscreen fixes + size increased
    * Replaced 0603 componentsn with 0805 counterparts for easier soldering
    [netnode_v3.brd, netnode_v3.sch]
2012-11-03 Added reset button.
    The reset button from Wuerth is a handy addition when developing firmware.
    [netnode_v3.brd, netnode_v3.sch]
2012-11-11 Final fixes for boardout.
    Added decoupling caps, fixed silkscreen, reviewed compontents
    [netnode_v3.brd, netnode_v3.sch]
2012-11-11 Added gerbers.
2012-11-11 Final gerber file commit of files sent to production. Fixed problems detected by PCB visualizer.
    [netnode_v3.brd, netnode_v3.sch]
2012-11-11 Added historical versions of netnode for completeness, added initial version of inboard.
    [ioboard v1.sch, netnode.brd, netnode.sch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]
2012-11-14 Intermediate commit of ioboard.
    [ioboard v1.sch]
2012-11-17 Updated IOboard with some more connectors and LEDs
    [ioboard v1.brd, ioboard v1.sch]
2012-11-18 First board layout
    [ioboard v1.brd, ioboard v1.sch]
2012-11-18 First routing attempt aith autorouter
    But no rules, just to know the routing is possible
    [ioboard v1.brd]
2013-01-30 Ordernumbers completed
    [ioboard v1.brd, ioboard v1.cfg, ioboard v1.dsn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]

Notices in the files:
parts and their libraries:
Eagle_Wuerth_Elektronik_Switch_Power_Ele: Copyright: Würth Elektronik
